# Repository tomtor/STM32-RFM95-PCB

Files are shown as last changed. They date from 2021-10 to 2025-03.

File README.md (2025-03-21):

# AVR128DB28
AVR Printed Circuit Board for creating IOT nodes with the RFM95 LORA chip.

See:
- https://www.thethingsnetwork.org/forum/t/avr128db28-pcb-with-rfm95/50864
- https://www.thethingsnetwork.org/labs/story/a-cheap-stm32-arduino-node

for background and old software samples.

This repository now has tested LMIC (https://github.com/tomtor/STM32-RFM95-PCB/tree/master/AVR128DBLora) and RadioLib (https://github.com/tomtor/STM32-RFM95-PCB/tree/master/AVR128_RadioLib) Arduino code for the AVR128DB board with the RFM95W.

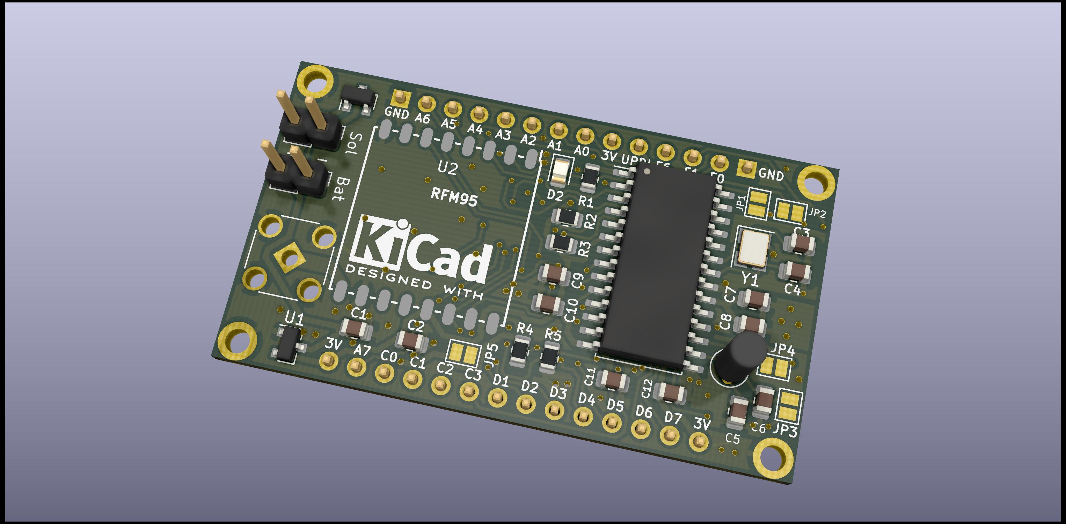
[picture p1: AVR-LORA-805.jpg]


Schema: https://github.com/tomtor/STM32-RFM95-PCB/raw/master/AVR-LORA.pdf

Note that most components are optional:

- A LED to flash
- I2C 4K7 pull up resistors
- A lot of capacitors (mounting a single 1uF will do in most situations)
- 32.768kHz crystal
- 24MHz crystal
- MCP1700 regulator with 1uA idle current
- Schottky diode for charging NiMH batteries from a solar panel
- Voltage divider for measuring battery voltage

Aisler link for producing 1206 board: https://aisler.net/p/EAZHDDHF

Aisler link for producing 0805 board: https://aisler.net/p/ZRKAROVP

# STM32-RFM95-PCB
STM32 Printed Circuit Board for creating IOT nodes with the RFM95 LORA chip

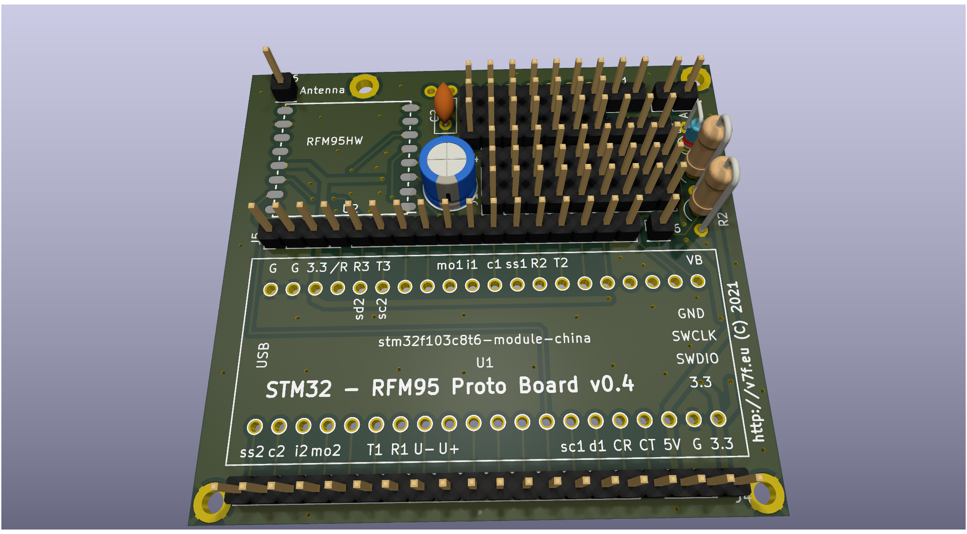
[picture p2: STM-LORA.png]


See:
- https://www.thethingsnetwork.org/labs/story/a-cheap-stm32-arduino-node
- https://gist.github.com/tomtor/c754355f1b98370e78b4025f236d990e (Arduino sketch)

You can order this board here:

https://aisler.net/p/CZGCIFFH

Credits:

https://github.com/myelin/myelin-kicad-libraries (STM32 module KiCad library)

https://github.com/mysensors-kicad/mysensors_symbols (RFM95 KiCad library)

https://github.com/novirium/ESPilot/blob/master/lib/ESPilot.pretty/RFM95.kicad_mod (RFM95 KiCad footprint)

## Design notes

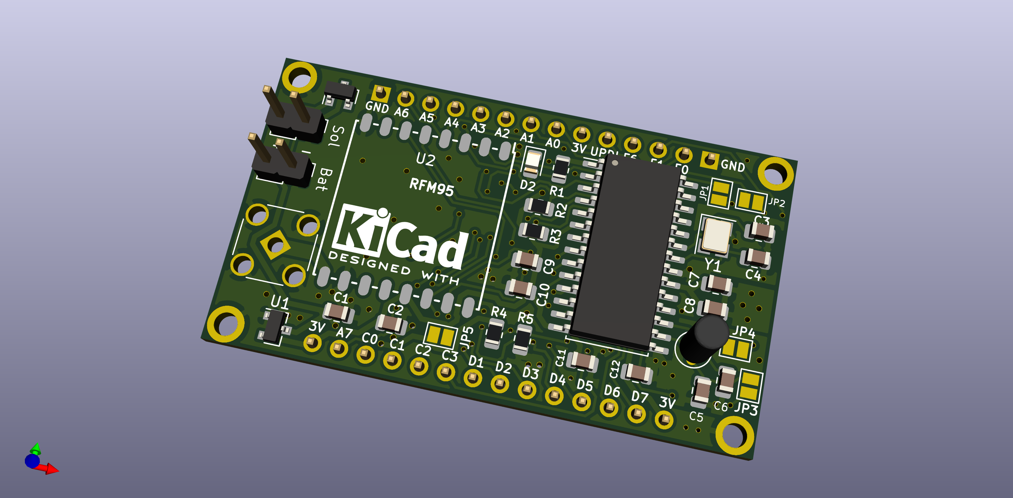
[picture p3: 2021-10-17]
AVR-LORA.png

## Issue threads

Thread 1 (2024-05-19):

BOM list?

radiohound, 2024-05-19:
Great project, and just what I am looking for in low power sleep capabilities. I was wondering if you had a BOM for this project (for the 805 version? I have purchased the boards, but I now need to buy the parts for it. Thank you

tomtor, 2025-05-25:
Sorry for the very late reply, hope your project was a success.

Some additional info for others who search for components.

I have no BOM because most components are optional or generic capacitors and resistors.

At Aisler you can also select (based on foot print) and order components when you order your board for reasonable prices.

These are the most important, the AVR128DB28 is the only non optional, and you must pay attention to ordering the correct foot print: SOIC

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

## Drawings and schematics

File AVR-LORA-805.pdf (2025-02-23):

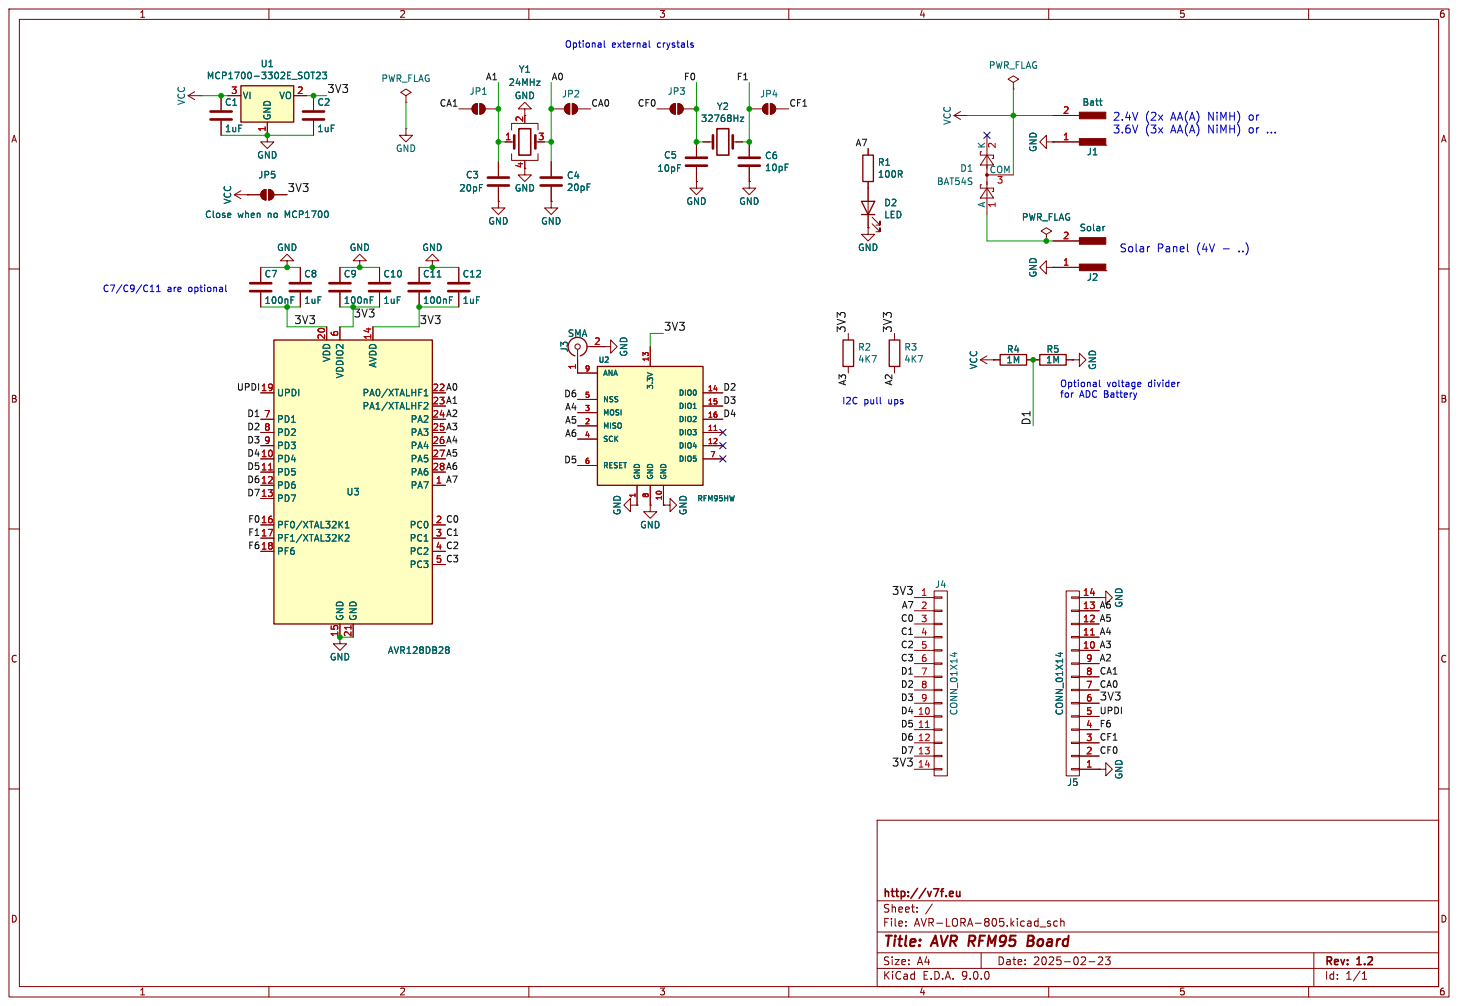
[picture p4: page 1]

JP5 Close when no MCP1700 GND
JP5 Close when no MCP1700 VCC

10pF GND GND GND GND

6 GND 15 GND 21 AVDD 14 PA0/XTALHF1 22 PA1/XTALHF2 23 PA2 24 PA3 25 PA4 26 PA5 27 PA6 28 PA7 1 PC0 2 PC1 3 PC2 4 PC3 5 U3 AVR128DB28 VCC

File: AVR-LORA-805.kicad_sch Sheet: / http://v7f.eu

Id: 1/1 Title: AVR RFM95 Board

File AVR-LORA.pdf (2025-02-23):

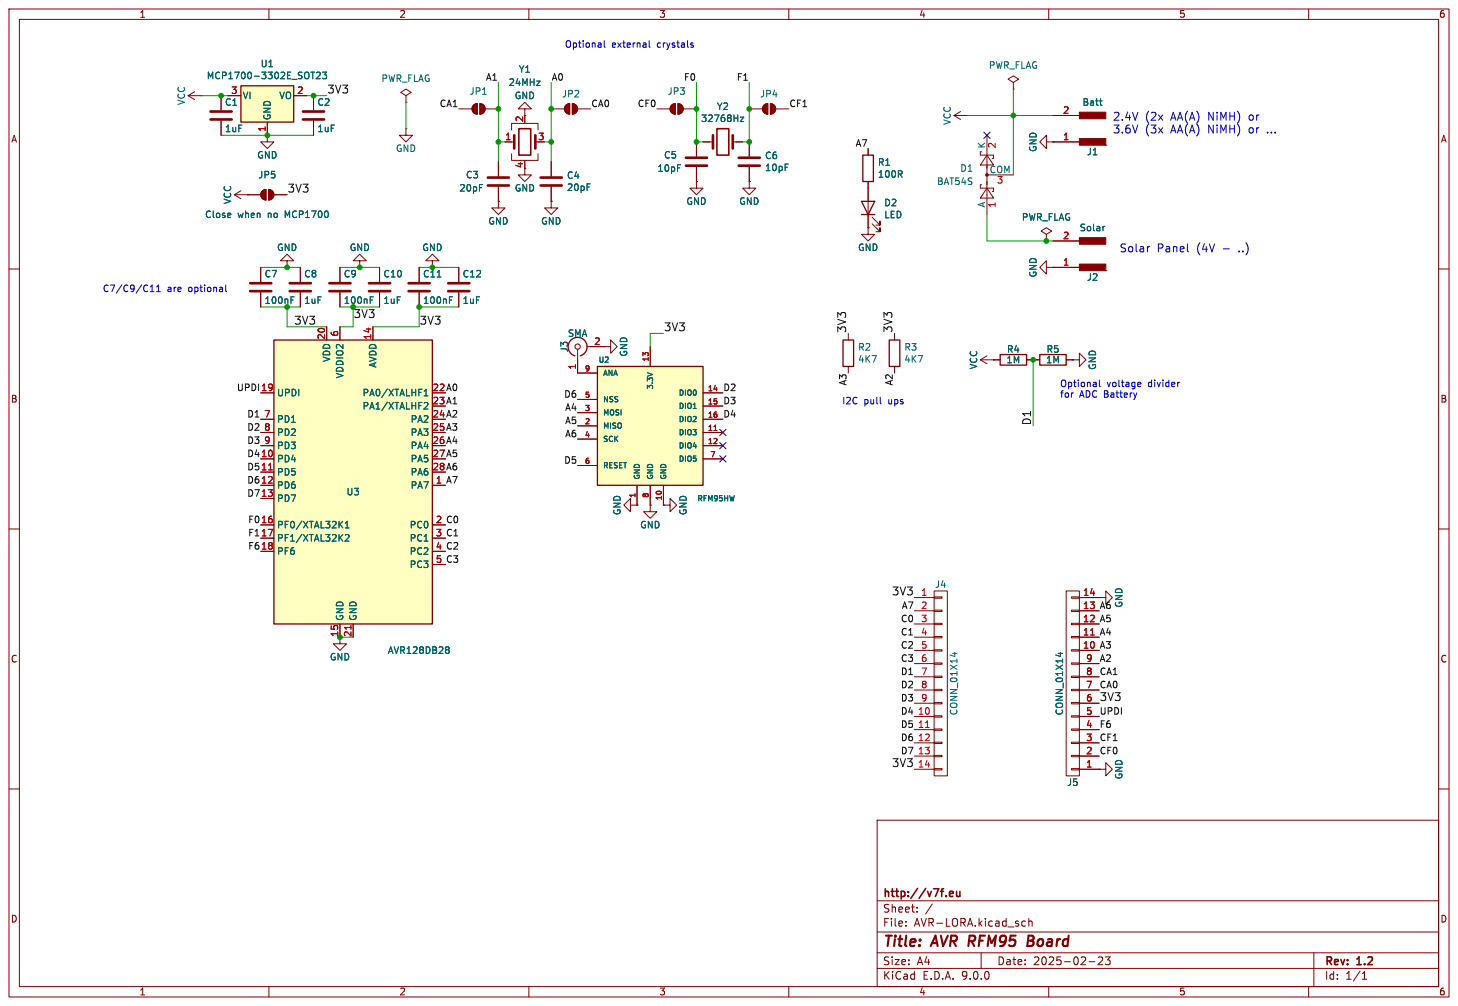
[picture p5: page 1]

1 VO 2 U1 MCP1700-3302E_SOT23 GND VCC GND

JP5 Close when no MCP1700 GND VCC
JP5 Close when no MCP1700

File: AVR-LORA.kicad_sch Sheet: / http://v7f.eu

Id: 1/1 Title: AVR RFM95 Board

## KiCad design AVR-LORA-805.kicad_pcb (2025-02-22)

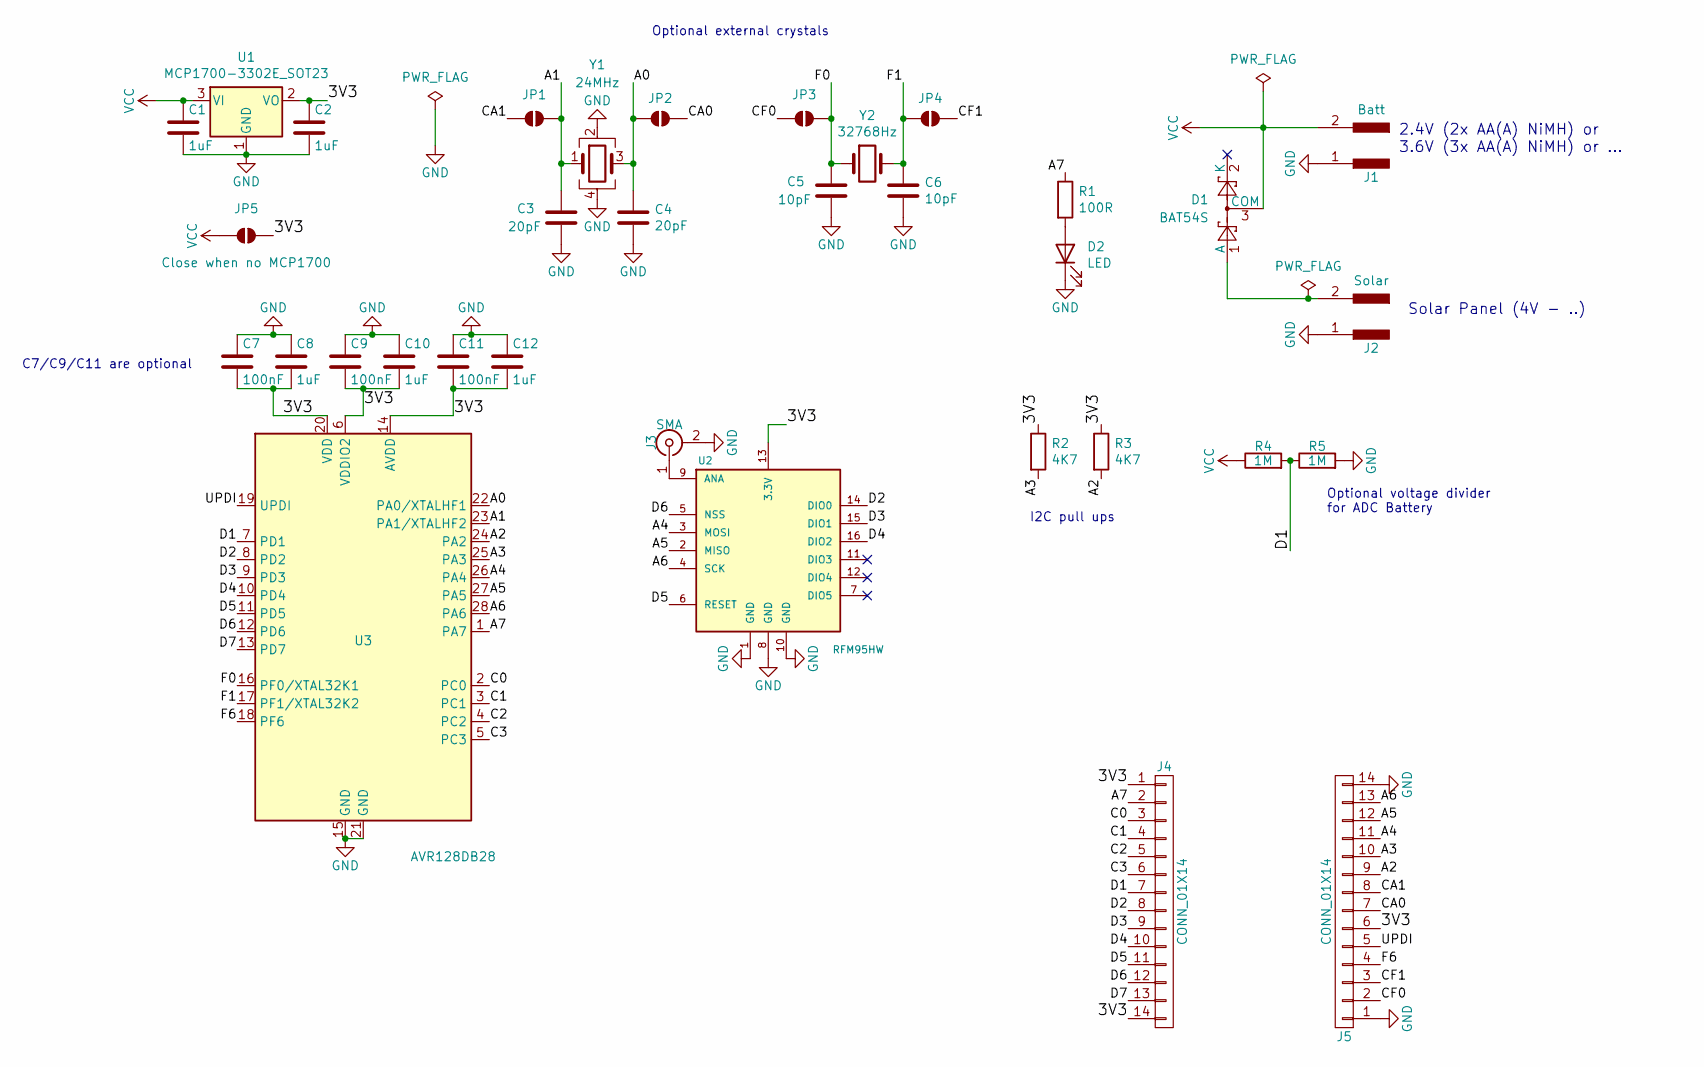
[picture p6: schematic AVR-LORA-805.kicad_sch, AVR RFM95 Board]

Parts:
C1, C2, C8, C10, C12: 1uF; C_0805_2012Metric
C3, C4: 20pF; C_0805_2012Metric
C5, C6: 10pF; C_0805_2012Metric
C7, C9, C11: 100nF; C_0805_2012Metric
D1: BAT54S; SOT-23
D2: LED; LED_0805_2012Metric
J1: Batt; PinHeader_1x02_P2.54mm_Vertical
J2: Solar; PinHeader_1x02_P2.54mm_Vertical
J3: SMA; SMA_Amphenol_132134_Vertical
J4, J5: CONN_01X14; PinHeader_1x14_P2.54mm_Vertical
JP1, JP2, JP3, JP4: SolderJumper_2_Open; SolderJumper-2_P1.3mm_Open_Pad1.0x1.5mm
JP5: Close when no MCP1700; SolderJumper-2_P1.3mm_Open_Pad1.0x1.5mm
R1: 100R; R_0805_2012Metric
R2, R3: 4K7; R_0805_2012Metric
R4, R5: 1M; R_0805_2012Metric
U1: MCP1700-3302E_SOT23; SOT-23
U2: RFM95HW; RFM95
U3: AVR128DB28; SOIC-28W_7.5x17.9mm_P1.27mm
Y1: 24MHz; Crystal_SMD_Abracon_ABM8G-4Pin_3.2x2.5mm
Y2: 32768Hz; Crystal_Round_D3.0mm_Vertical

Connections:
/3V3: C2.1, C7.2, C8.2, C9.2, C10.2, C11.2, C12.2, J4.1, J4.14, J5.6, JP5.2 (B), R2.1, R3.1, U1.2 (VO), U2.13 (3.3V), U3.6 (VDDIO2), U3.14 (AVDD), U3.20 (VDD)
/A0: C4.1, JP2.1 (A), U3.22 (PA0/XTALHF1), Y1.3
/A1: C3.1, JP1.1 (A), U3.23 (PA1/XTALHF2), Y1.1
/A2: J5.9, R3.2, U3.24 (PA2)
/A3: J5.10, R2.2, U3.25 (PA3)
/A4: J5.11, U2.3 (MOSI), U3.26 (PA4)
/A5: J5.12, U2.2 (MISO), U3.27 (PA5)
/A6: J5.13, U2.4 (SCK), U3.28 (PA6)
/A7: J4.2, R1.1, U3.1 (PA7)
/C0: J4.3, U3.2 (PC0)
/C1: J4.4, U3.3 (PC1)
/C2: J4.5, U3.4 (PC2)
/C3: J4.6, U3.5 (PC3)
/CA0: J5.7, JP2.2 (B)
/CA1: J5.8, JP1.2 (B)
/CF0: J5.2, JP3.2 (B)
/CF1: J5.3, JP4.2 (B)
/D1: J4.7, R4.2, R5.1, U3.7 (PD1)
/D2: J4.8, U2.14 (DIO0), U3.8 (PD2)
/D3: J4.9, U2.15 (DIO1), U3.9 (PD3)
/D4: J4.10, U2.16 (DIO2), U3.10 (PD4)
/D5: J4.11, U2.6 (RESET), U3.11 (PD5)
/D6: J4.12, U2.5 (NSS), U3.12 (PD6)
/D7: J4.13, U3.13 (PD7)
/F0: C5.1, JP3.1 (A), U3.16 (PF0/XTAL32K1), Y2.1
/F1: C6.1, JP4.1 (A), U3.17 (PF1/XTAL32K2), Y2.2
/F6: J5.4, U3.18 (PF6)
/UPDI: J5.5, U3.19 (UPDI)
GND: C1.2, C2.2, C3.2, C4.2, C5.2, C6.2, C7.1, C8.1, C9.1, C10.1, C11.1, C12.1, D2.1 (K), J1.1, J2.1, J3.2 (Ext), J5.1, J5.14, R5.2, U1.1 (GND), U2.1 (GND), U2.8 (GND), U2.10 (GND), U3.15 (GND), U3.21 (GND), Y1.2, Y1.4
unnamed: D1.1 (A), J2.2
unnamed: D2.2 (A), R1.2
unnamed: J3.1 (In), U2.9 (ANA)
VCC: C1.1, D1.3 (COM), J1.2, JP5.1 (A), R4.1, U1.3 (VI)

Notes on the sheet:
Optional external crystals
Solar Panel (4V - ..)
C7/C9/C11 are optional
I2C pull ups
2.4V (2x AA(A) NiMH) or 3.6V (3x AA(A) NiMH) or ...
Optional voltage divider for ADC Battery

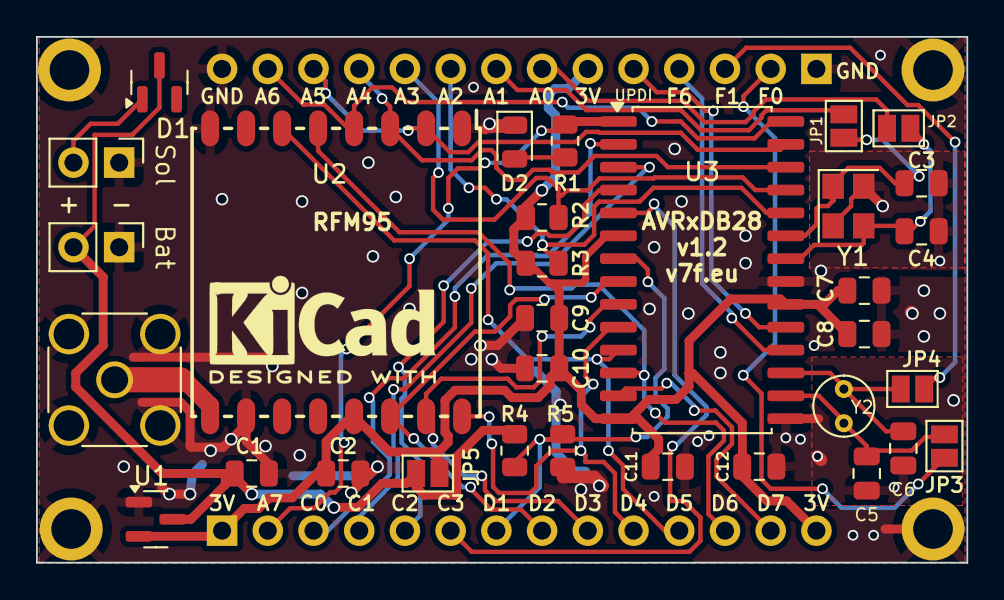
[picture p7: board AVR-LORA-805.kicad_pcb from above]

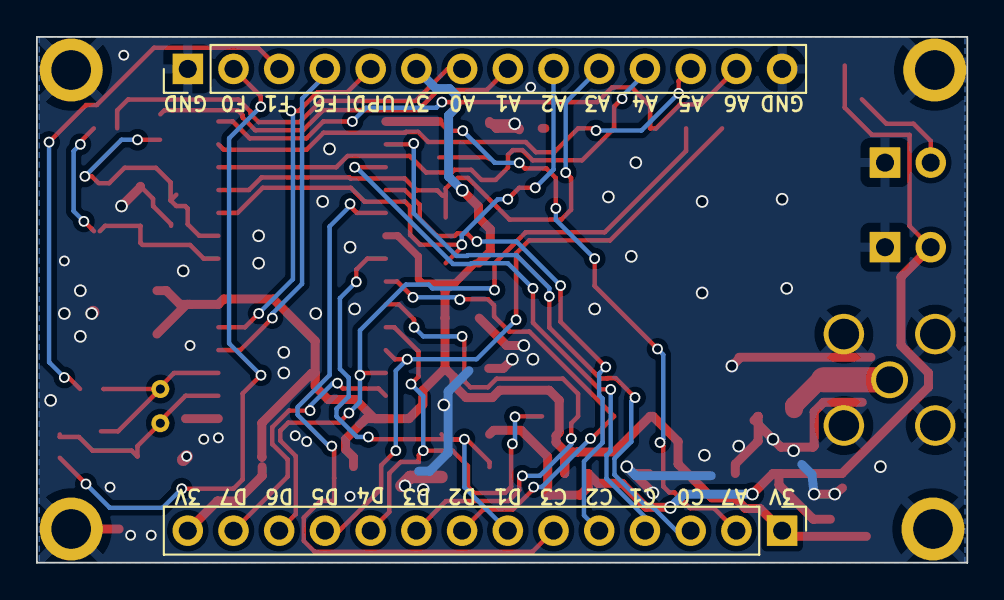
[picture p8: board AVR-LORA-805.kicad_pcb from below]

Board: 2 copper layers, 51.7 x 29.2 mm, 34 parts (2 on the bottom side), 33 nets.

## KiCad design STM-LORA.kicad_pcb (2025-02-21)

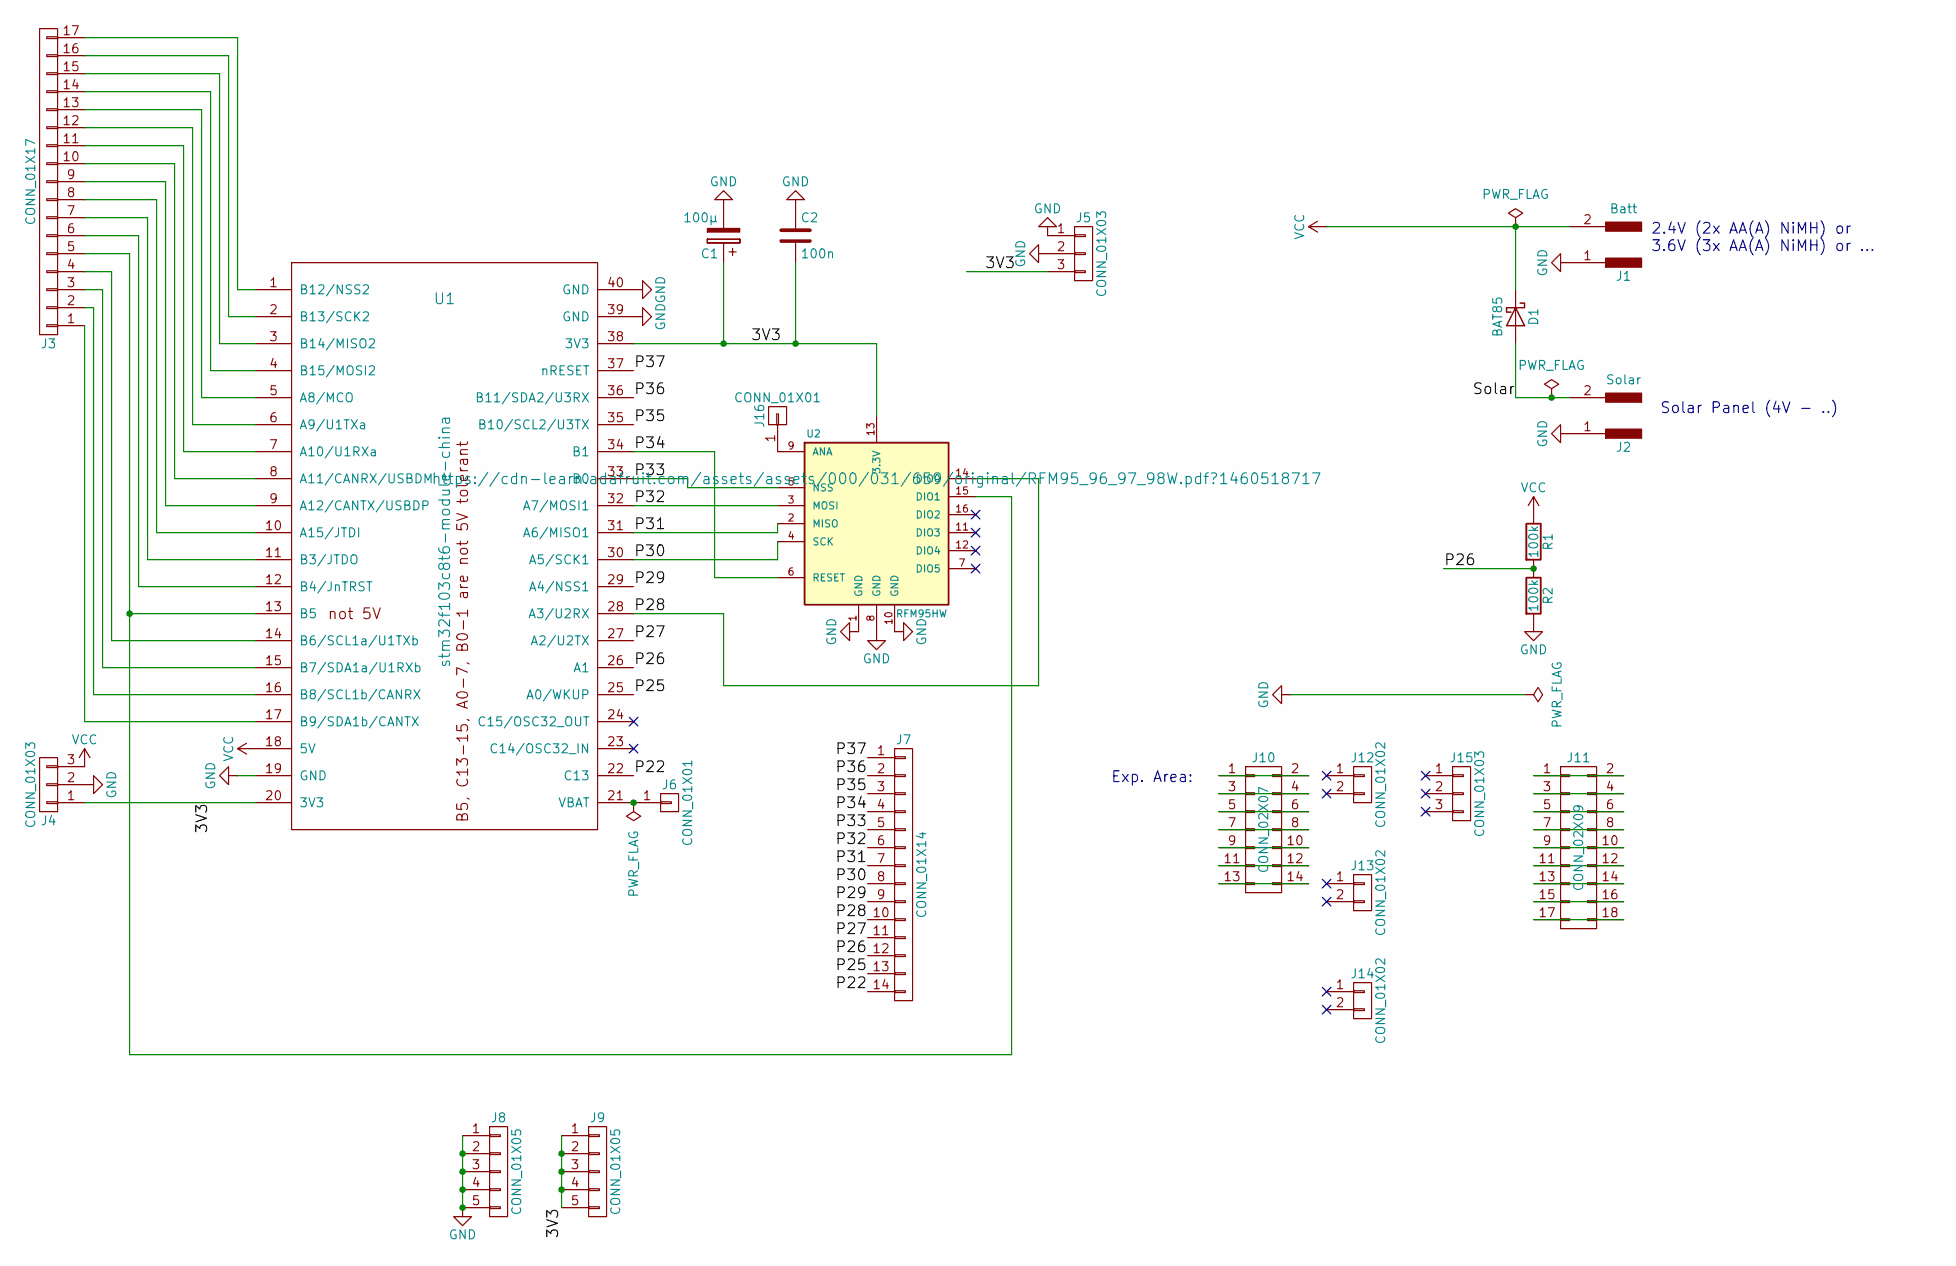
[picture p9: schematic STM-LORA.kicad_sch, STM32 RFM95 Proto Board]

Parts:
C1: 100µ; CP_Radial_D6.3mm_P2.50mm
C2: 100n; C_Disc_D5.0mm_W2.5mm_P2.50mm
D1: BAT85; D_DO-35_SOD27_P2.54mm_Vertical_AnodeUp
J1: Batt; PinHeader_1x02_P2.54mm_Vertical
J2: Solar; PinHeader_1x02_P2.54mm_Vertical
J3: CONN_01X17; PinHeader_1x17_P2.54mm_Vertical
J4, J5, J15: CONN_01X03; PinHeader_1x03_P2.54mm_Vertical
J6, J16: CONN_01X01; PinHeader_1x01_P2.54mm_Vertical
J7: CONN_01X14; PinHeader_1x14_P2.54mm_Vertical
J8, J9: CONN_01X05; PinHeader_1x05_P2.54mm_Vertical
J10: CONN_02X07; PinHeader_2x07_P2.54mm_Vertical
J11: CONN_02X09; PinHeader_2x09_P2.54mm_Vertical
J12, J13, J14: CONN_01X02; PinHeader_1x02_P2.54mm_Vertical
R1, R2: 100k; R_Axial_DIN0309_L9.0mm_D3.2mm_P2.54mm_Vertical
U1: stm32f103c8t6-module-china
U2: RFM95HW; RFM95

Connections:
/3V3: C1.1, C2.2, J4.1, J5.3, J9.1, J9.2, J9.3, J9.4, J9.5, U1.20 (3V3), U1.38 (3V3), U2.13 (3.3V)
/P22: J7.14, U1.22 (C13)
/P25: J7.13, U1.25 (A0/WKUP)
/P26: J7.12, R1.2, R2.1, U1.26 (A1)
/P27: J7.11, U1.27 (A2/U2TX)
/P28: J7.10, U1.28 (A3/U2RX), U2.14 (DIO0)
/P29: J7.9, U1.29 (A4/NSS1)
/P30: J7.8, U1.30 (A5/SCK1), U2.4 (SCK)
/P31: J7.7, U1.31 (A6/MISO1), U2.2 (MISO)
/P32: J7.6, U1.32 (A7/MOSI1), U2.3 (MOSI)
/P33: J7.5, U1.33 (B0), U2.5 (NSS)
/P34: J7.4, U1.34 (B1), U2.6 (RESET)
/P35: J7.3, U1.35 (B10/SCL2/U3TX)
/P36: J7.2, U1.36 (B11/SDA2/U3RX)
/P37: J7.1, U1.37 (nRESET)
/Solar: D1.2 (A), J2.2
GND: C1.2, C2.1, J1.1, J2.1, J4.2, J5.1, J5.2, J8.1, J8.2, J8.3, J8.4, J8.5, R2.2, U1.19 (GND), U1.39 (GND), U1.40 (GND), U2.1 (GND), U2.8 (GND), U2.10 (GND)
unnamed: J3.1, U1.17 (B9/SDA1b/CANTX)
unnamed: J3.2, U1.16 (B8/SCL1b/CANRX)
unnamed: J3.3, U1.15 (B7/SDA1a/U1RXb)
unnamed: J3.4, U1.14 (B6/SCL1a/U1TXb)
unnamed: J3.5, U1.13 (B5), U2.15 (DIO1)
unnamed: J3.6, U1.12 (B4/JnTRST)
unnamed: J3.7, U1.11 (B3/JTDO)
unnamed: J3.8, U1.10 (A15/JTDI)
unnamed: J3.9, U1.9 (A12/CANTX/USBDP)
unnamed: J3.10, U1.8 (A11/CANRX/USBDM)
unnamed: J3.11, U1.7 (A10/U1RXa)
unnamed: J3.12, U1.6 (A9/U1TXa)
unnamed: J3.13, U1.5 (A8/MCO)
unnamed: J3.14, U1.4 (B15/MOSI2)
unnamed: J3.15, U1.3 (B14/MISO2)
unnamed: J3.16, U1.2 (B13/SCK2)
unnamed: J3.17, U1.1 (B12/NSS2)
unnamed: J6.1, U1.21 (VBAT)
unnamed: J10.1, J10.2
unnamed: J10.3, J10.4
unnamed: J10.5, J10.6
unnamed: J10.7, J10.8
unnamed: J10.9, J10.10
unnamed: J10.11, J10.12
unnamed: J10.13, J10.14
unnamed: J11.1, J11.2
unnamed: J11.3, J11.4
unnamed: J11.5, J11.6
unnamed: J11.7, J11.8
unnamed: J11.9, J11.10
unnamed: J11.11, J11.12
unnamed: J11.13, J11.14
unnamed: J11.15, J11.16
unnamed: J11.17, J11.18
unnamed: J16.1, U2.9 (ANA)
VCC: D1.1 (K), J1.2, J4.3, R1.1, U1.18 (5V)

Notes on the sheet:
Exp. Area:
2.4V (2x AA(A) NiMH) or 3.6V (3x AA(A) NiMH) or ...
Solar Panel (4V - ..)

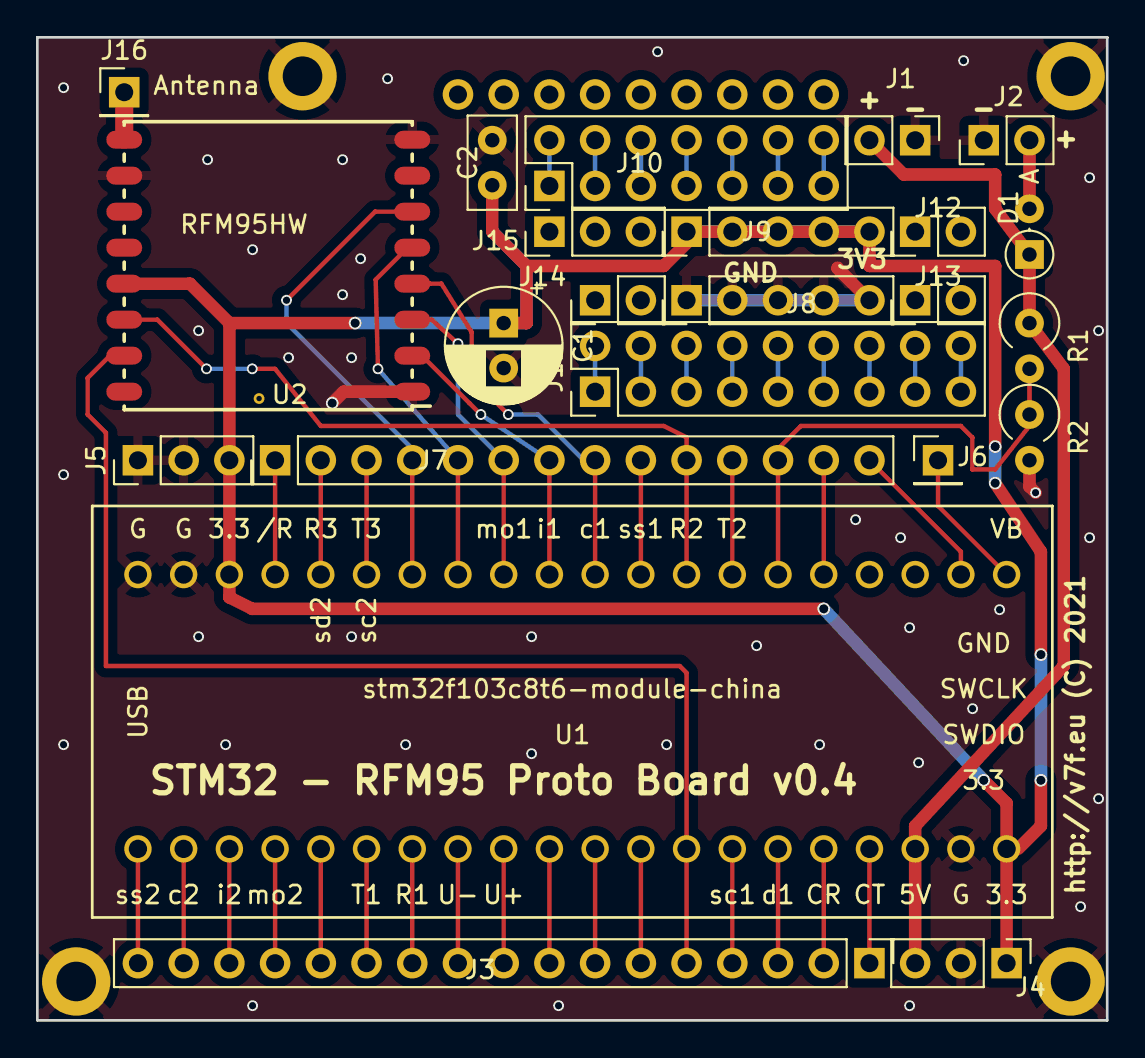
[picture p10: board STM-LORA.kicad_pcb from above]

Board: 2 copper layers, 59.4 x 54.6 mm, 23 parts (0 on the bottom side), 53 nets.

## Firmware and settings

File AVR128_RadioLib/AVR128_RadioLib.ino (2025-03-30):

/*
 * Adapted RadioLib example for AVR128DB with rain bucket counter
 *
 * Power usage 2uA in sleep mode. Also enters 2uA (radio) sleep when waiting for LoraWan reply.
 */

#include "config.h"

#include <avr/sleep.h>

int uplinkIntervalSeconds = 1 * 60;    // minutes x seconds

#define LED             PIN_PA7
#define COUNT_PIN       PIN_PA2

//#define TIMING_PIN      PIN_PD7

#define ON_TIME         3 // LED ON blink time in ms

#define RTC_PERIOD	    0x8000 // Overflow at 32768 ticks from RTC
#define RTC_MILLIS	    1000   // That matches 1000ms

#define USE_OSC         0      // 1 if no crystal or 0 when using a 32768 crystal

volatile unsigned counter;  // Counts pin transitions to low

typedef uint8_t u1_t;

void fillDEVEUI (u1_t* buf) { // Fetch AVR128 serial numbers
  // use chip ID:
  u1_t *serial= (u1_t*)&SIGROW.SERNUM0;
  for (byte i= 0; i <= 7; i++)
    buf[i] = serial[i] ^ serial[8+i];
  // Make locally registered:
  buf[0] = (buf[0] & ~0x3) | 0x1;

  Serial.print(F("DevEui: "));
  for (int i = 7; i >= 0; i--) {
    Serial.printHex((uint8_t)buf[i]);
    Serial.print(' ');
  }
  Serial.println("");
}

void wdt_enable() {
  while (WDT.STATUS & WDT_SYNCBUSY_bm)
	;
  _PROTECTED_WRITE(WDT.CTRLA, WDT_PERIOD_8KCLK_gc); // no window, 8 seconds
}

void wdt_reset() {
  __asm__ __volatile__ ("wdr"::);
}

void wdt_disable() {
  while (WDT.STATUS & WDT_SYNCBUSY_bm)
	;
  _PROTECTED_WRITE(WDT.CTRLA, 0);
}

void RTC_init(void)
{
  /* Initialize RTC: */
  while (RTC.STATUS > 0)
    ;                                   /* Wait for all register to be synchronized */
  RTC.PER = RTC_PERIOD - 1;		/* 1 sec overflow */
#if USE_OSC
  RTC.CLKSEL = RTC_CLKSEL_OSC32K_gc;    /* 32.768kHz Internal Ultra-Low-Power Oscillator (OSCULP32K) */
#else
  _PROTECTED_WRITE(CLKCTRL.XOSC32KCTRLA, CLKCTRL_ENABLE_bm | CLKCTRL_LPMODE_bm);

  while (RTC.STATUS > 0) ;

  RTC.CLKSEL = RTC_CLKSEL_XOSC32K_gc;   /* 32.768kHz External Oscillator */
#endif

  // For overflow ticks while sleeping:
  RTC.INTCTRL = RTC_OVF_bm;

  RTC.CTRLA |= RTC_PRESCALER_DIV1_gc | RTC_RUNSTDBY_bm | RTC_RTCEN_bm;
}

volatile uint8_t sleep_cnt;

volatile uint8_t secs, minutes;
volatile uint8_t hours;
volatile uint16_t time_s;

ISR(RTC_CNT_vect)
{
  if (RTC.INTFLAGS & RTC_CMP_bm) {
    sleep_cnt--;
    RTC.INTFLAGS = RTC_CMP_bm;            /* Clear interrupt flag by writing '1' (required) */
  }

  if (RTC.INTFLAGS & RTC_OVF_bm) {
    time_s++;
    if (secs < 59)
      secs += 1;
    else {
      secs = 0;
      if (minutes < 59)
        minutes++;
      else {
        minutes = 0;
#if 1
        if (hours < 23)
          hours++;
        else
          hours = 0;
#endif
      }  
    }
    RTC.INTFLAGS = RTC_OVF_bm;          /* Clear interrupt flag by writing '1' (required) */
  }
}

void sleepDelay(uint16_t n)
{
#ifdef TIMING_PIN
  digitalWriteFast(TIMING_PIN, HIGH);
#endif
  while (RTC.STATUS /* & RTC_CMPBUSY_bm */)  // Wait for new settings to synchronize
    ;

  uint32_t tdelay;
  noInterrupts();
  uint16_t cnt = RTC.CNT;
  RTC.CMP = (cnt + (tdelay = (n * 32UL) + uint16_t(n / 4 * 3))) & (RTC_PERIOD-1); // With this calculation every multiple of 4ms is exact!
  // Note 20011 ms = 655360 ticks = 20 overflows exactly, so CMP will be set to the current CNT and this works OK
  // 9005 will set CMP to CNT+1

  if (RTC.CNT == RTC.CMP) {
    tdelay -= RTC_PERIOD;
  } else if (((RTC.CMP - cnt) & (RTC_PERIOD-1)) <= 2) { // overflow is/was near, 4Mhz clock or faster
    while (RTC.CNT != RTC.CMP) // Wait for it...
      ;
    tdelay -= RTC_PERIOD;
  }

  interrupts();

  RTC.INTCTRL |= RTC_CMP_bm; // This might trigger a pending interrupt, so do this before assigning sleep_cnt!
#if RTC_PERIOD != 0x8000
  sleep_cnt = tdelay / RTC_PERIOD + 1; // Calculate number of wrap arounds (overflows)
#else
  sleep_cnt = 2 * (tdelay >> 16) + ((tdelay & 0x8000) ? 2 : 1); // 10 times faster...
#endif
  uint64_t start = millis();
  while (sleep_cnt) {
    sleep_cpu();
    wdt_reset();
  }
  set_millis(start + n);

  RTC.INTCTRL &= ~RTC_CMP_bm;
#ifdef TIMING_PIN
  digitalWriteFast(TIMING_PIN, LOW);
#endif
}

void count_rain()
{
    static uint16_t prev;
    if (counter == 0)
      time_s = 0;
    if (time_s - prev > 1 || counter == 0) {
      counter++;
      prev = time_s;
    }
}

#if 1
unsigned int getBandgap ()
{
  analogReference(INTERNAL1V024);
  analogRead(ADC_VDDDIV10); // drop first
  return analogRead(ADC_VDDDIV10);
}
#endif

#if GET_BATTERY
unsigned int getBattery ()
{
  analogReference(VDD);

  analogRead(PIN_PD1);
  unsigned int val = analogRead(PIN_PD1);

  // 3.3v regulator with voltage divider (820k/820k):
  const float Vref = 3300;
  const unsigned long scale = Vref*2;
  unsigned int results = scale * val / 0x400;

  return results;
}
#endif

#if 0
unsigned int getTemp()
{
  analogReference(INTERNAL2V048);
  analogRead(ADC_TEMPERATURE);
  uint16_t adc_reading = analogRead(ADC_TEMPERATURE);
  uint16_t sigrow_offset = SIGROW.TEMPSENSE1; // Read unsigned value from signature row
  uint16_t sigrow_slope = SIGROW.TEMPSENSE0; // Read unsigned value from signature row
  uint32_t temp = sigrow_offset - adc_reading;
  temp *= sigrow_slope; // Result will overflow 16-bit variable
  temp += 0x0800; // Add 4096/2 to get correct rounding on division below
  temp >>= 12; // Round off to nearest degree in Kelvin, by dividing with 2^12 (4096)
  return temp-273;
}
#endif

void blinkN(uint8_t n, uint8_t l = LED)
{
  for (uint8_t i = 0; i < n; i++) {
    digitalWriteFast(l, HIGH);
    sleepDelay(ON_TIME);
    digitalWriteFast(l, LOW);
    sleepDelay(700);
  }
}

void blinkDec(uint8_t d)
{
  blinkN(d / 10);
  sleepDelay(1500);
  blinkN(d % 10);
  sleepDelay(3000);
}

void blinkDec3(uint16_t d)
{
  blinkN(d / 100);
  sleepDelay(1500);
  blinkDec(d % 100);
}

void sleepDelayRadio(uint32_t t)
{
  if (t > 500)
    radio.sleep();
  sleepDelay(t);
}

void sleepDelayLong(uint32_t t)
{
  const int interval = 16000;
  while (t > interval) {
    sleepDelay(interval);
    t -= interval;
    blinkN(1);
  }
  sleepDelay(t);
  blinkN(1);
}


void setup() {
  Serial.begin(38400, SERIAL_TX_ONLY);
  Serial.println("Starting");
  delay(100);
  wdt_enable();

  TCA0.SPLIT.CTRLA = 0;                 // If you aren't using TCA0 for anything

  RTC_init();                           /* Initialize the RTC timer */
  set_sleep_mode(SLEEP_MODE_STANDBY);
  sleep_enable();                       /* Enable sleep mode, but not going to sleep yet */

  pinMode(PIN_PA0, INPUT_PULLUP);
  pinMode(PIN_PA1, INPUT_PULLUP);
  pinMode(PIN_PA2, INPUT_PULLUP);
  pinMode(PIN_PA3, INPUT_PULLUP);
  pinMode(PIN_PA4, INPUT_PULLUP);
  pinMode(PIN_PA5, INPUT_PULLUP);
  pinMode(PIN_PA6, INPUT_PULLUP);
  pinMode(PIN_PA7, INPUT_PULLUP);
  
#if GET_BATTERY
  pinMode(PIN_PD1, INPUT);
#else
  pinMode(PIN_PD1, INPUT_PULLUP);
#endif
  pinMode(PIN_PD2, INPUT_PULLUP);
  pinMode(PIN_PD3, INPUT_PULLUP);
  pinMode(PIN_PD4, INPUT); 		// DIO2
  pinMode(PIN_PD5, INPUT_PULLUP);
  pinMode(PIN_PD6, INPUT_PULLUP);
  pinMode(PIN_PD7, INPUT_PULLUP);
#ifdef TIMING_PIN
  pinMode(TIMING_PIN, OUTPUT);
#endif
  
  //pinMode(PIN_PC0, INPUT_PULLUP);	// Serial out
  pinMode(PIN_PC1, INPUT_PULLUP);
  pinMode(PIN_PC2, INPUT_PULLUP);
  pinMode(PIN_PC3, INPUT_PULLUP);
  
  pinMode(PIN_PF0, INPUT_PULLUP);
  pinMode(PIN_PF1, INPUT_PULLUP);
  
  pinMode(LED, OUTPUT);

  pinConfigure(COUNT_PIN, (PIN_DIR_INPUT | PIN_PULLUP | PIN_ISC_FALL));
  attachInterrupt(digitalPinToInterrupt(COUNT_PIN), count_rain, FALLING);

  for (byte i = 0; i < 3; i++) {
    blinkN(1, LED);
  }

  Serial.flush();
  Serial.println(F("\nSetup ... "));

  Serial.println(F("Initialise the radio"));
  radio.reset();
  int16_t state = radio.begin();
  debug(state != RADIOLIB_ERR_NONE, F("Initialise radio failed"), state, true);

  fillDEVEUI((uint8_t*)&devEUI);
  // Setup the OTAA session information
  //state = node.beginOTAA(joinEUI, devEUI, nwkKey, appKey);
  state = node.beginOTAA(joinEUI, devEUI, NULL, appKey);
  debug(state != RADIOLIB_ERR_NONE, F("Initialise node failed"), state, true);

  Serial.println(F("Join ('login') the LoRaWAN Network"));
  state = node.activateOTAA();
  debug(state != RADIOLIB_LORAWAN_NEW_SESSION, F("Join failed"), state, true);

  Serial.println(F("Ready!\n"));
#if !USE_OSC
  Serial.println(F("Using 32768 crystal!"));
  node.setSleepFunction(sleepDelayRadio); // Needs a 32768 crystal
#endif
}

struct {
  unsigned short temp;
  unsigned short rain;
  byte power;
  byte rate2;
} mydata;

#define voltagePin    PA1

void readData()
{
    mydata.power = getBandgap() - 100;
    noInterrupts(); // prevent race condition with rain interrupts
    mydata.rain = counter;
    mydata.temp = (hours << 11) | (minutes << 5) | (secs >> 1);
    counter = 0;
    interrupts();
}

void loop() {
  Serial.println(F("Sending uplink"));

  readData();
  
  // Perform an uplink
  uint8_t reply[4];
  size_t replylen;
  int16_t state = node.sendReceive((uint8_t*)&mydata, sizeof(mydata), 1, reply, &replylen);
  debug(state < RADIOLIB_ERR_NONE, F("Error in sendReceive"), state, false);

  // Check if a downlink was received 
  // (state 0 = no downlink, state 1/2 = downlink in window Rx1/Rx2)
  if(state > 0) {
    Serial.println(F("Received a downlink"));
    if (replylen == 1) {
      mydata.rate2= reply[0];
      uplinkIntervalSeconds= (1 << reply[0]);
    } else if (replylen == 3) {
      hours = reply[0];
      minutes = reply[1];
      secs = reply[2];
    }
  } else {
    Serial.println(F("No downlink received"));
  }

  Serial.print(F("Next uplink in "));
  Serial.print(uplinkIntervalSeconds);
  Serial.println(F(" seconds\n"));
  Serial.flush();
 
  radio.sleep();

  // Wait until next uplink - observing legal & TTN FUP constraints
  for (byte w= 0; w <= 2; w++) {
    sleepDelayLong(uplinkIntervalSeconds * 1000UL);  // delay needs milli-seconds
    if (counter)
      break;
  }
 
  Serial.printf(F("Time: %02d:%02d:%02d\r\n"), hours, minutes, secs);
}

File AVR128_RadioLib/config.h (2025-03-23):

#ifndef _RADIOLIB_EX_LORAWAN_CONFIG_H
#define _RADIOLIB_EX_LORAWAN_CONFIG_H

#undef Serial
#define Serial Serial1

#include <RadioLib.h>

#define DIO1_PIN PIN_PD3
#define DIO0_PIN PIN_PD2
#define RESET_PIN PIN_PD5
#define SCK_PIN PIN_PA6		// SCK for SPI
#define MOSI_PIN PIN_PA4	// MOSI for SPI
#define MISO_PIN PIN_PA5 	// MISO for SPI
#define CS_PIN PIN_PD6   	// CS for SPI1 === NSS

// first you have to set your radio model and pin configuration
// this is provided just as a default example
SX1276 radio = new Module(CS_PIN, DIO0_PIN, RESET_PIN, DIO1_PIN);

// if you have RadioBoards (https://github.com/radiolib-org/RadioBoards)
// and are using one of the supported boards, you can do the following:
/*
#define RADIO_BOARD_AUTO
#include <RadioBoards.h>

Radio radio = new RadioModule();
*/

// how often to send an uplink - consider legal & FUP constraints - see notes
//const uint32_t uplinkIntervalSeconds = 1UL * 60UL;    // minutes x seconds

#include "secrets.h"

// joinEUI - previous versions of LoRaWAN called this AppEUI
// for development purposes you can use all zeros - see wiki for details
#ifndef RADIOLIB_LORAWAN_JOIN_EUI
#define RADIOLIB_LORAWAN_JOIN_EUI  REPLACE
#endif

// the Device EUI & two keys can be generated on the TTN console 
#ifndef RADIOLIB_LORAWAN_DEV_EUI   // Replace with your Device EUI
#define RADIOLIB_LORAWAN_DEV_EUI   0
#endif
#ifndef RADIOLIB_LORAWAN_APP_KEY   // Replace with your App Key 
#define RADIOLIB_LORAWAN_APP_KEY   REPLACE
#endif
#ifndef RADIOLIB_LORAWAN_NWK_KEY   // Put your Nwk Key here
#define RADIOLIB_LORAWAN_NWK_KEY   NULL
#endif

// for the curious, the #ifndef blocks allow for automated testing &/or you can
// put your EUI & keys in to your platformio.ini - see wiki for more tips

// regional choices: EU868, US915, AU915, AS923, AS923_2, AS923_3, AS923_4, IN865, KR920, CN470
const LoRaWANBand_t Region = EU868;

// subband choice: for US915/AU915 set to 2, for CN470 set to 1, otherwise leave on 0
const uint8_t subBand = 0;

// ============================================================================
// Below is to support the sketch - only make changes if the notes say so ...

// copy over the EUI's & keys in to the something that will not compile if incorrectly formatted
uint64_t joinEUI =   RADIOLIB_LORAWAN_JOIN_EUI;
uint64_t devEUI  =   RADIOLIB_LORAWAN_DEV_EUI;
uint8_t appKey[] = { RADIOLIB_LORAWAN_APP_KEY };
uint8_t nwkKey[] = { RADIOLIB_LORAWAN_NWK_KEY };

// create the LoRaWAN node
LoRaWANNode node(&radio, &Region, subBand);
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

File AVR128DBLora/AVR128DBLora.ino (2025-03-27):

/*
This example AVR128DB script for LORA counts events on a specified pin and sends the count with LoraWAN.

I use it for a rain bucket counter.

The script is tuned for low power consumption (4 microampere sleep current including RFM95 chip)

Tom Vijlbrief (C) 2025
*/

#include <arduino_lmic.h>
#include <arduino_lmic_hal_boards.h>
#include <arduino_lmic_hal_configuration.h>
#include <arduino_lmic_lorawan_compliance.h>
#include <arduino_lmic_user_configuration.h>

#include <lmic.h>
#include <hal/hal.h>

#include <avr/sleep.h>

#define RTC_PERIOD	0x8000 // Overflow at 32768 ticks from RTC
#define RTC_MILLIS	1000   // That matches 1000ms

#define LED             PIN_PA7

#define COUNT_PIN       PIN_PA2

#define GET_BATTERY     0 // Read battery when using a voltage regulator

#define USE_LORA        // Activate LORA RFM95 chip

#define USE_TIMER       // Use timer in idle sleep, instead of standby sleep
#define SLEEPINT	      // Do not count PIT interrupts but use RTC interrupt at exact time

#undef  Serial
#define Serial          Serial1 // I use serial port 1 (C0/C1 = Tx/Rx)

unsigned TX_INTERVAL =  300;

#define ON_TIME         3 // LED ON blink time in ms

//#define SLEEP_ADJUST    1070 // My 32768 clock is 4.5% to fast, so 1024 millis should be 1070

#include "my_lora.h"    // this file has my APP settings

//static const u1_t APPEUI[8] PROGMEM = {  }; // reversed 8 bytes of AppEUI registered with ttnctl
void os_getArtEui (u1_t* buf) { memcpy_P(buf, APPEUI, 8);}

//static const unsigned char APPKEY[16] PROGMEM = {  }; // non-reversed 16 bytes of the APPKEY used when registering a device with ttnctl register DevEUI AppKey
void os_getDevKey (u1_t* buf) {  memcpy_P(buf, APPKEY, 16);}

static u1_t DEVEUI[8]={ }; // Filled by fillDEVUI()
void os_getDevEui (u1_t* buf) { memcpy(buf, DEVEUI, 8);}

void fillDEVEUI (u1_t* buf) {
  // use chip ID:
  u1_t *serial= (u1_t*)&SIGROW.SERNUM0;
  for (byte i= 0; i <= 7; i++)
    buf[i] = serial[i] ^ serial[8+i];
  // Make locally registered:
  buf[0] = (buf[0] & ~0x3) | 0x1;

  Serial.print("DevEui: ");
  for (int i = 7; i >= 0; i--) {
    Serial.printHex((uint8_t)buf[i]);
    Serial.print(' ');
  }
  Serial.println("");
}

struct {
  unsigned short temp;
  unsigned short rain;
  byte power;
  byte rate2;
} mydata;

volatile unsigned counter;  // Counts pin transitions to low

static osjob_t sendjob;

// Pin mapping
const lmic_pinmap lmic_pins = {
    .nss = PIN_PD6,
    .rxtx = LMIC_UNUSED_PIN,
    .rst = PIN_PD5,
    .dio = {PIN_PD2, PIN_PD3, PIN_PD4},
};

void do_send(osjob_t* j){
    // Check if there is not a current TX/RX job running
    if (LMIC.opmode & OP_TXRXPEND) {
        Serial.println(F("OP_TXRXPEND, not sending"));
    } else {
        static unsigned long last_send;
        // Serial.println(TX_INTERVAL);
        // Serial.println(last_send);
        // Serial.println(millis());
        if (last_send && counter == 0
        && ((unsigned long) (millis() - last_send)) < (unsigned long)(TX_INTERVAL * 2500L)) { // send every 2.5 intervals (rounds to 3) when counter == 0 (no rain)
            Serial.println("Skip");
            os_setTimedCallback(&sendjob, os_getTime()+sec2osticks(TX_INTERVAL), do_send);
            return;
        }
        mydata.power = getBandgap() - 100;
        noInterrupts(); // prevent race condition with rain interrupts
        mydata.rain = counter;
        counter = 0;
        interrupts();
        // Prepare upstream data transmission at the next possible time.
        LMIC_setTxData2(1, (uint8_t*)&mydata, sizeof(mydata), 0);
        Serial.println(F("Packet queued"));
        last_send= millis();
    }
    // Next TX is scheduled after TX_COMPLETE event.
}


bool in_tx;
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

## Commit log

2017-04-01 Added power components
    [STM-LORA.kicad_pcb, STM-LORA.sch]
2017-04-02 update STM32 lib, add connectors
    [STM-LORA.kicad_pcb, STM-LORA.sch]
2017-04-02 start traces
    [STM-LORA.kicad_pcb, STM-LORA.sch]
2017-04-02 version 0.1
    [STM-LORA.kicad_pcb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]
2017-04-02 Update edges, silk screen
    [STM-LORA.kicad_pcb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]
2017-04-02 0.1 version sent to production
    [STM-LORA.kicad_pcb, STM-LORA.sch]
2017-04-03 added drill file
2017-04-03 Change and add exp headers to schema (0.2)
    [STM-LORA.kicad_pcb, STM-LORA.sch]
2017-04-03 hide/clear connector labels
    [STM-LORA.kicad_pcb]
2017-04-03 increase power track/via size
    [STM-LORA.kicad_pcb]
2017-04-04 gnd backplane
    [STM-LORA.kicad_pcb]
2017-04-04 Improve GND backplane
    [STM-LORA.kicad_pcb]
2017-04-04 Add NC to exp area
    [STM-LORA.sch]
2017-04-04 improve GND plane and double 3V3 track
    [STM-LORA.kicad_pcb]
2017-04-04 reposition capacitor
    [STM-LORA.kicad_pcb]
2017-04-05 clean up files
    [STM-LORA-B.Cu.gbr, STM-LORA-B.Mask.gbr, STM-LORA-Edge.Cuts.gbr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]
2017-04-06 Layout silk screen
    [STM-LORA.kicad_pcb]
2017-04-07 add front ground plane
    [STM-LORA.kicad_pcb]
2017-04-07 edit front plane and readd fp-lib-table
    [STM-LORA.kicad_pcb, STM-LORA.sch]
2017-04-11 reposition labels
    [STM-LORA.kicad_pcb]
2017-05-29 Add pdf for layout, layers and schema
    [STM-LORA.kicad_pcb]
2017-05-31 Add 0.2 zip with Gerber files
2017-06-10 Move edge labels to center
    [STM-LORA.kicad_pcb]
2017-06-10 move edge
    [STM-LORA.kicad_pcb]
2017-06-10 reset grid origin
    [STM-LORA.kicad_pcb]
2021-05-02 Version 0.4 Add antenna hole
    [STM-LORA.kicad_pcb, STM-LORA.sch]
2021-05-03 Convert libs for Kicad 5.1
    [STM-LORA.kicad_pcb, STM-LORA.sch]
2021-08-17 Add AVR schema
    [AVR-LORA.sch]
2021-08-17 Add AVR connectors
    [AVR-LORA.sch]
2021-08-17 Add AVR pull ups
    [AVR-LORA.sch]
2021-08-18 Add AVR crystals
    [AVR-LORA.sch]
2021-08-18 Add footprints to AVR
    [AVR-LORA.kicad_pcb, AVR-LORA.sch]
2021-08-19 Layout AVR
    [AVR-LORA.kicad_pcb, AVR-LORA.sch]
2021-08-19 Start routing AVR
    [AVR-LORA.kicad_pcb]
2021-08-20 Clean DRC AVR
    [AVR-LORA.kicad_pcb]
2021-08-21 Cleanup and add pin labels AVR
    [AVR-LORA.kicad_pcb, AVR-LORA.sch]
2021-08-21 Add PDF and PNG to AVR
    [AVR-LORA.kicad_pcb]
2021-08-21 Update 32768 config and PDF and PNG for AVR
    [AVR-LORA.kicad_pcb, AVR-LORA.sch]
2021-08-21 Update 24MHz crystal config and PDF and PNG for AVR
    [AVR-LORA.kicad_pcb, AVR-LORA.sch]
2021-08-21 TTN version
    [AVR-LORA.kicad_pcb]
2021-08-21 cleanup back silk screen AVR
    [AVR-LORA.kicad_pcb]
2021-08-21 Ground mounting holes AVR
    [AVR-LORA.kicad_pcb]
2021-08-22 Better 24Mhz layout AVR
    [AVR-LORA.kicad_pcb, AVR-LORA.sch]
2021-08-22 Add SMA connector
    [AVR-LORA.kicad_pcb, AVR-LORA.sch]
2021-08-22 Update copper fill
    [AVR-LORA.kicad_pcb]
2021-08-22 Minor cleanups with labeling
    [AVR-LORA.kicad_pcb]
2021-08-22 Ground SMA
    [AVR-LORA.kicad_pcb]
2021-08-22 Bigger SMA central pad for soldering wire
    [AVR-LORA.kicad_pcb]
2021-08-22 Grow board slightly
    [AVR-LORA.kicad_pcb]
2021-08-23 Improve ground plane
    [AVR-LORA.kicad_pcb, AVR-LORA.sch]
2021-08-23 Improve silk screen
    [AVR-LORA.kicad_pcb]
2021-08-24 GND SMA connector in schema
    [AVR-LORA.kicad_pcb, AVR-LORA.sch]
2021-08-25 Tune antenne trace to 50 Ohm
    [AVR-LORA.kicad_pcb]
2021-08-28 Add 805 AVR variant
    [AVR-LORA-805.kicad_pcb, AVR-LORA.kicad_pcb]
2021-08-28 Improve silk 805
    [AVR-LORA-805.kicad_pcb]
2021-08-28 Improve routes 805
    [AVR-LORA-805.kicad_pcb]
2021-09-03 Add KiCAD logo
    [AVR-LORA-805.kicad_pcb]
2021-09-19 Add capacitors to 32768 crystal for 0805 version
    [AVR-LORA-805.kicad_pcb, AVR-LORA.kicad_pcb, AVR-LORA.sch]
2021-09-19 Add capacitors to 32768 crystal for both versions
    [AVR-LORA-805.kicad_pcb, AVR-LORA.kicad_pcb]
2021-09-19 1.1 version
    [AVR-LORA-805.kicad_pcb]
2021-09-20 Silk and routing improvements
    [AVR-LORA-805.kicad_pcb, AVR-LORA.kicad_pcb]
2021-09-20 crystal grounding
    [AVR-LORA-805.kicad_pcb, AVR-LORA.kicad_pcb]
2021-10-17 Demo Arduino sketch
2021-10-17 GND tracks
    [AVR-LORA-805.kicad_pcb, AVR-LORA.kicad_pcb]
2021-10-17 GND VIAs
    [AVR-LORA-805.kicad_pcb, AVR-LORA.kicad_pcb]
2025-02-21 Kicad v9.0.0 version
    [AVR-LORA-805.kicad_pcb, AVR-LORA-805.kicad_sch, AVR-LORA.kicad_pcb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]
2025-02-21 Fix warnings on AVR LORA
    [AVR-LORA.kicad_pcb]
2025-02-22 Minor cleanups AVR 805 version
    [AVR-LORA-805.kicad_pcb, AVR-LORA-805.kicad_sch, AVR-LORA.kicad_sch]
2025-02-23 new schemas and PDFs
    [AVR-LORA-805.kicad_sch, AVR-LORA.kicad_sch]
2025-02-23 Change battery measure pin
2025-02-24 Update README.md
    Add STM32 LORA board image
2025-02-24 Fix millis() adjustment in sleepDelay()
    [AVR128DB.ino]
2025-03-02 LED on when in TX
2025-03-03 add timer mode
2025-03-04 fix no rain timing
    [AVR128DBLora.ino]
2025-03-04 fix more no rain timing
    [AVR128DBLora.ino]
2025-03-05 Use timer TCB in standby instead of idle
2025-03-09 Kicad9 STM-Lora schematic
    [STM-LORA.kicad_sch]
2025-03-10 Add RadioLib example for STM32
2025-03-10 DevId is retrieved from STM32 ROM
2025-03-19 Fix order of int enable
    [AVR128DBLora.ino]
2025-03-20 comment on pending interrupt
2025-03-21 Update README.md
    Refer to code samples
2025-03-23 fix dio1 current leak
2025-03-23 fix dio1 and interrupts
    [AVR128DBLora.ino, AVR128_RadioLib.ino, config.h]

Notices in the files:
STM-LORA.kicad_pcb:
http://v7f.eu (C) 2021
